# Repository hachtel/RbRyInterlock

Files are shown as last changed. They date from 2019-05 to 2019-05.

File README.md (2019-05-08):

# RbRyInterlock
This project is a PCB centered around the ESP8266 board.The board is intended to take an analog signal on the A0 pin (e.g. from a photodiode), discriminate if the signal is above some threshold and toggle a digital output. Since the Moglabs TA interlock references its own +5V and GND we are using this control signal to modulate a mechanical relay to short or open the interlock.
## A few key features:
- A level converter is required as the mechanical relay switches at a voltage larger than the microprocessor supplies, thus we boost the 3.3V signal to 5V. 
- There is a BNC header (updated using JQI BNC connector footprint for better mechanical stability) to bring in the signal from the photodiode. 
- To ensure that the board is a single layer we have inserted a ground plane. 
- The original design used linear voltage regulators to condition +15V down to +5V. These were running too hot, so we have added solder pads 1/2 for +5V/GND. We have found that a standard AC/DC wall adapter works well for this purpose.

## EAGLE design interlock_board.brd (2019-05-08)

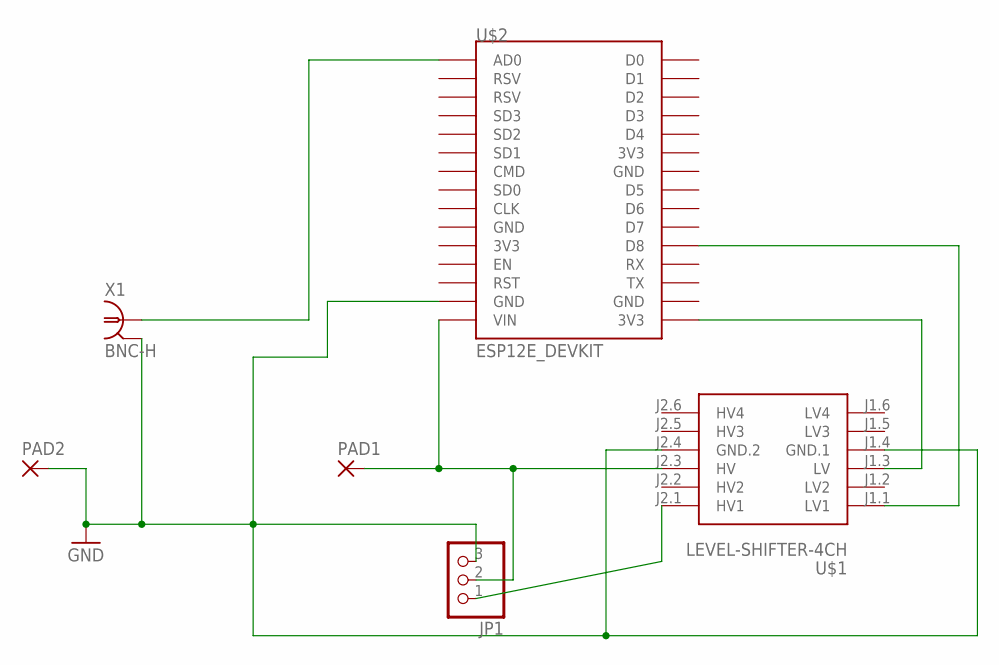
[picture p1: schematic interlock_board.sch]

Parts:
JP1: PINHD-1X3; 1X03
PAD1, PAD2: 2,54/0,9
U$1: LEVEL-SHIFTER-4CH
U$2: ESP12E_DEVKIT
X1: BNC-H; BNC90

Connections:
GND: JP1.3, PAD2.1, U$1.J1.4 (GND.1), U$1.J2.4 (GND.2), U$2.GND@1 (GND), X1.2
unnamed: JP1.2, PAD1.1, U$1.J2.3 (HV), U$2.VIN
unnamed: U$1.J1.3 (LV), U$2.3V3@2 (3V3)
unnamed: U$1.J1.1 (LV1), U$2.D8
unnamed: U$2.AD0, X1.1
unnamed: JP1.1, U$1.J2.1 (HV1)

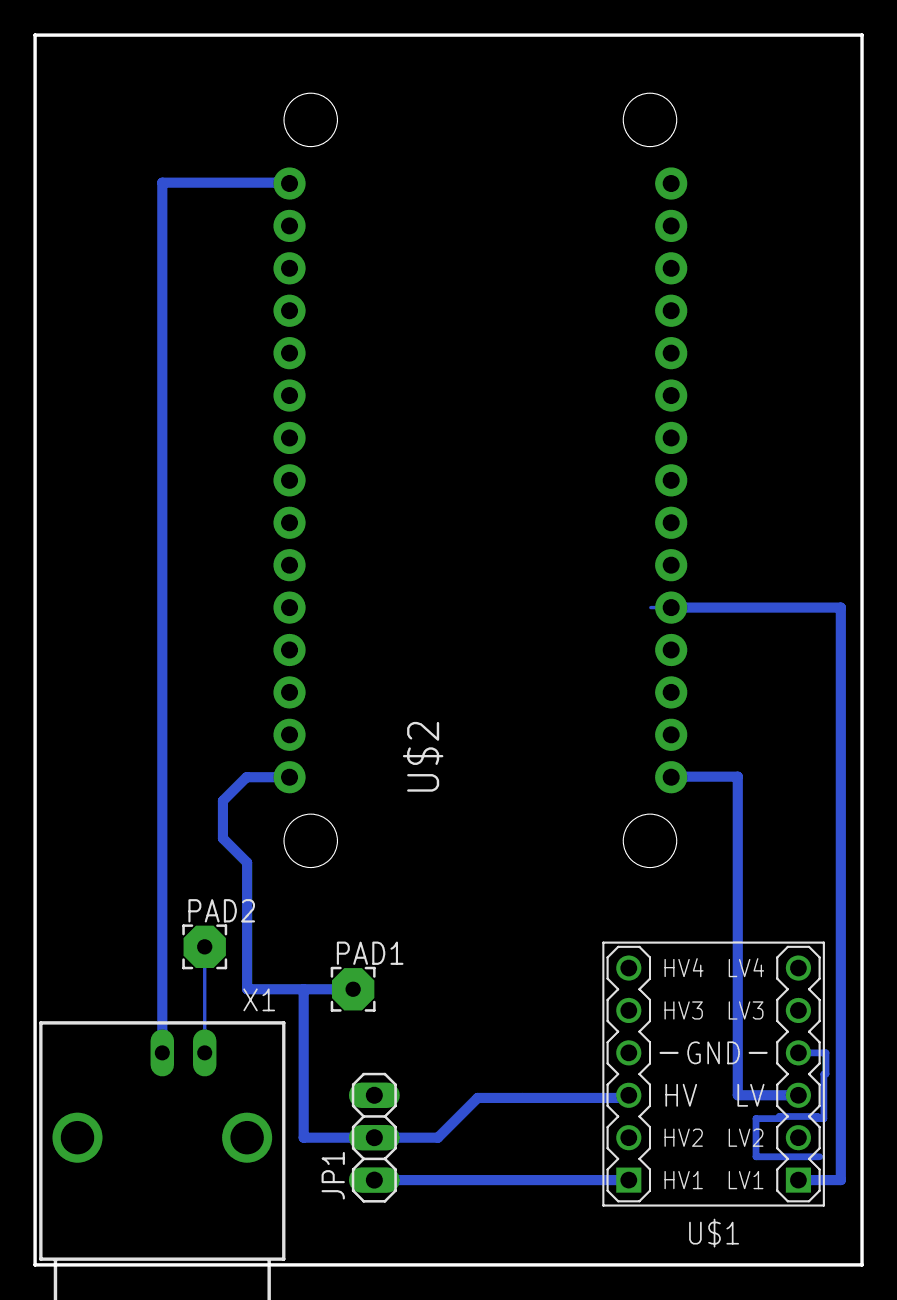
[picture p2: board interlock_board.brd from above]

Board: 2 copper layers, 49.5 x 73.7 mm, 6 parts (0 on the bottom side), 6 nets.

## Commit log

2019-05-01 Added EAGLE files
    [interlock_board.brd, interlock_board.sch]
2019-05-01 Update interlock_board.brd
    Moved various wires so they are not as close to the various pins on the board.
    [interlock_board.brd]
2019-05-08 Update with Alessandro's help
    This update increases the copper trace size from 0.008" to 0.024" and moves them to the bottom layer, uses an updated BNC connector footprint (from JQI library) for better mechanical stability, and increased some hole sizes from 800 micron to 0.04".
    [interlock_board.brd, interlock_board.sch]
2019-05-08 Update README.md
    Added new information after printing with Alessandro.

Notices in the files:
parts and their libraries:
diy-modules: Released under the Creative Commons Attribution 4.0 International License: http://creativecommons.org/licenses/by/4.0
